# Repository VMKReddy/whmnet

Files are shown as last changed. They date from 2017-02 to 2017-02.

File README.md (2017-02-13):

# whmnet

The whmnet project consists in:
- A wireless sensor network which performs temperature, atmospheric pressure and relative humidity measurements
- A gateway which receives the measurements and pass them to a Raspberry Pi
- A Raspberry Pi which is connected to the Internet, posting measurements on a webserver
- A web server hosting the measurements database and a web application to display the date

# The Sensor

The wireless sensor is a custom PCB based on:
- A STM32L0 ARM-Cortex M0 microcontroler which gathers data from sensors and send them over the air
- SHT21 Relative Humdity Sensor - I2C
- MS5637 Barometric Pressure Sensor - I2C
- CC1101 868MHz transceiver from Texas Instruments - SPI
- On-board 868MHz ceramic antenna and IPC device (balun + filter + match)
- All of this is powered by a CR2450 lithium coin cell downconverted to 2.1V by TPS62730 ultra-low-power DC-DC converter

The wireless sensor performs a measurement every 5 minutes and goes back to low-power mode between each measurement, achieving an ultra-low-power average consumption of 5µA leading to several months of battery life.

The PCB design files are available in the [SensorBoard](./SensorBoard/) directory. It has been designed with Altium Designer.

The MCU firmware is available in the [Sensor](./Sensor/) directory. [SW4STM32](http://www.openstm32.org) Eclipse based IDE from AC6 has been used. The toolchain is GCC-based, and the (free) IDE is part of the STMicroelectronics Open Development Environment. BSP has been generated with [STM32CubeMX](http://www.st.com/en/development-tools/stm32cubemx.html) tool and the [STM32CubeL0](http://www.st.com/en/embedded-software/stm32cubel0.html) open-source library is used.

# The Gateway

The gateway consists in:
- A custom board for wireless reception
- A Raspberry Pi 2 model B

## Gateway RF Board

The custom board includes:
- An STM32L0 microcontroler
- A CC1120 RF transceiver for wireless communication
- A green LED indicating radio packet Rx

The STM32L0 reports the measurements from wireless sensors to the Raspberry Pi using the serial port.

The PCB design files are available in the [GatewayBoard](./GatewayBoard/) directory.
The MCU firmware of the Gateway Board is available in the [Gateway](./Gateway/) directory.

## Raspberry Pi

The Raspberry Pi:
- Receives measurements from the custom board over the UART
- Check data validity (by controlling CRC values)
- Push the data on a webserver on the internet

Failures, hangs, loss of internet connection, etc. are all taken care of by dedicated scripts and watchdogs which perform data backup, retries, process monitoring and eventually reboots.

# The webserver

The webserver, hosted on the internet:
- stores data coming from the Gateway
- run a web application for data display

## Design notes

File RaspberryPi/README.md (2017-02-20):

## Raspberry Pi software

### Description

A Raspberry Pi model B+ running Raspbian Jessie is used to post the measurements on the web.
The python script readGateway.py is used to communicate with the Gateway.

The Gateway reports measurements coming from wireless sensors to the Raspberry Pi through the serial port (pins 8 & 10 of the Raspberry Pi model B header).

Communication is unidirectionnal (Gateway --> Raspberry Pi).

After receiving raw data from the Gateway, the script extracts measurements (temperature, pressure, RH) and posts them on a dedicated server on the web.

### Dependencies

The script is run with python 2.7.6.
The following external packages are needed:
- [requests](http://docs.python-requests.org/en/master/) (to perform http requests)
- [crcmod](https://pypi.python.org/pypi/crcmod) (for custom CRC calculations)

You can install these two packages with pip for instance.

### Configuration

Edit the configTemplate.py script to match your configuration (logging level, webserver parameters, ...). Then rename it to config.py or modify readGateway.py to import the right script. 

### Monitoring script execution

#### Monitoring script

The shell script [readGatewayMonitor](readGatewayMonitor) is used to restart the python script if it crashes.
Modify the paths to match your configuration if you want to use it.

#### Crontab

A crontab entry is used to start the readGatewayMonitor script at boot time.

Use ```sudo crontab -e``` to edit the crontab and then add the following entry (change path to math your installation):
```
@reboot /home/pi/templog_gateway/readGatewayMonitor
```

#### Logrotate

The python script logs data to a log file each time a message is received from the Gateway, or only on errors, depending on the logger configuration (see script).

Logrotate tool is used to keep logfile small and delete oldest logs automatically. It is not shipped with Raspbian by default so you may need to install it manually with ```apt-get install```.

Configuration of logrotate for our use is in [logrotate.d](logrotate.d/).
Simply copy [templog](logrotate.d/templog) to ```/etc/logrotate.d/``` on your Pi, and edit it so the paths match your installation.

### Additionnal considerations

In the actual setup, the Raspberry Pi is left unattented for several months. The hardware watchdog has been configured on the Pi to reboot the system in case of a major failure or undetected bugs remaining in the python script.

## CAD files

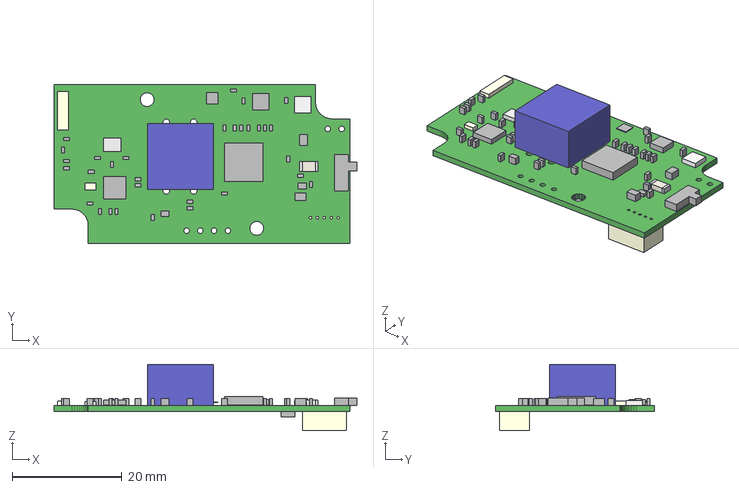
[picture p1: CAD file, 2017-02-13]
SensorBoard/Project Outputs for SensorNode/PCB.step
55.3 x 29.0 x 12.1 mm
Board
Extruded x 50

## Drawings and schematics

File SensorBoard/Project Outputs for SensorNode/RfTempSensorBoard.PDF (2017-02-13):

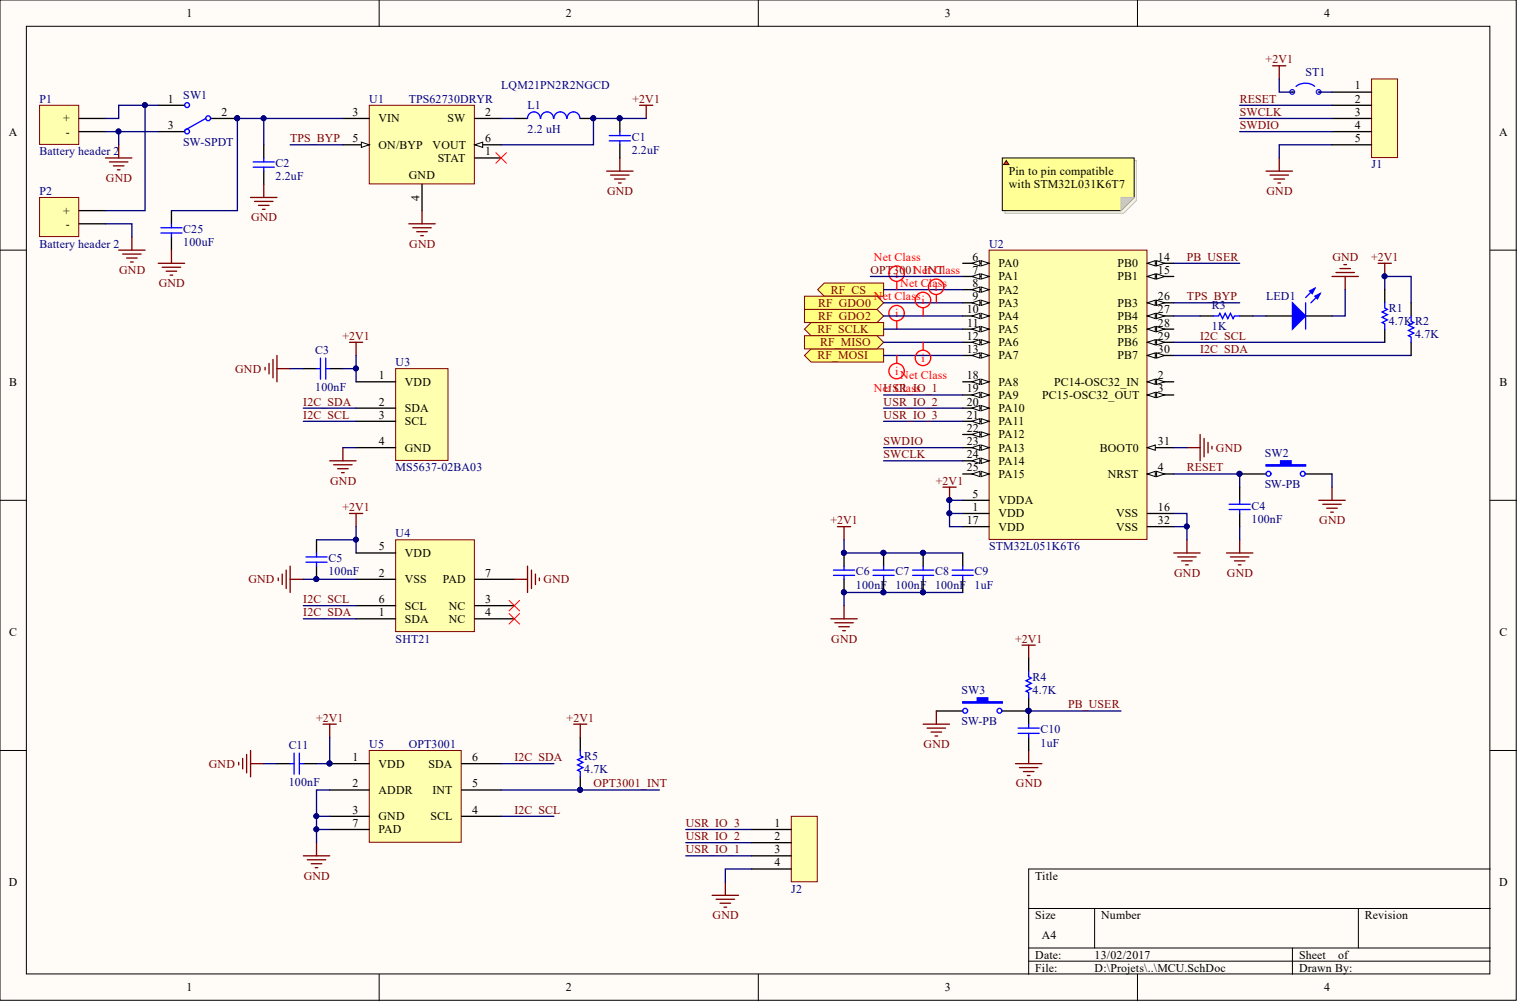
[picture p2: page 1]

Pin to pin compatible
with STM32L031K6T7

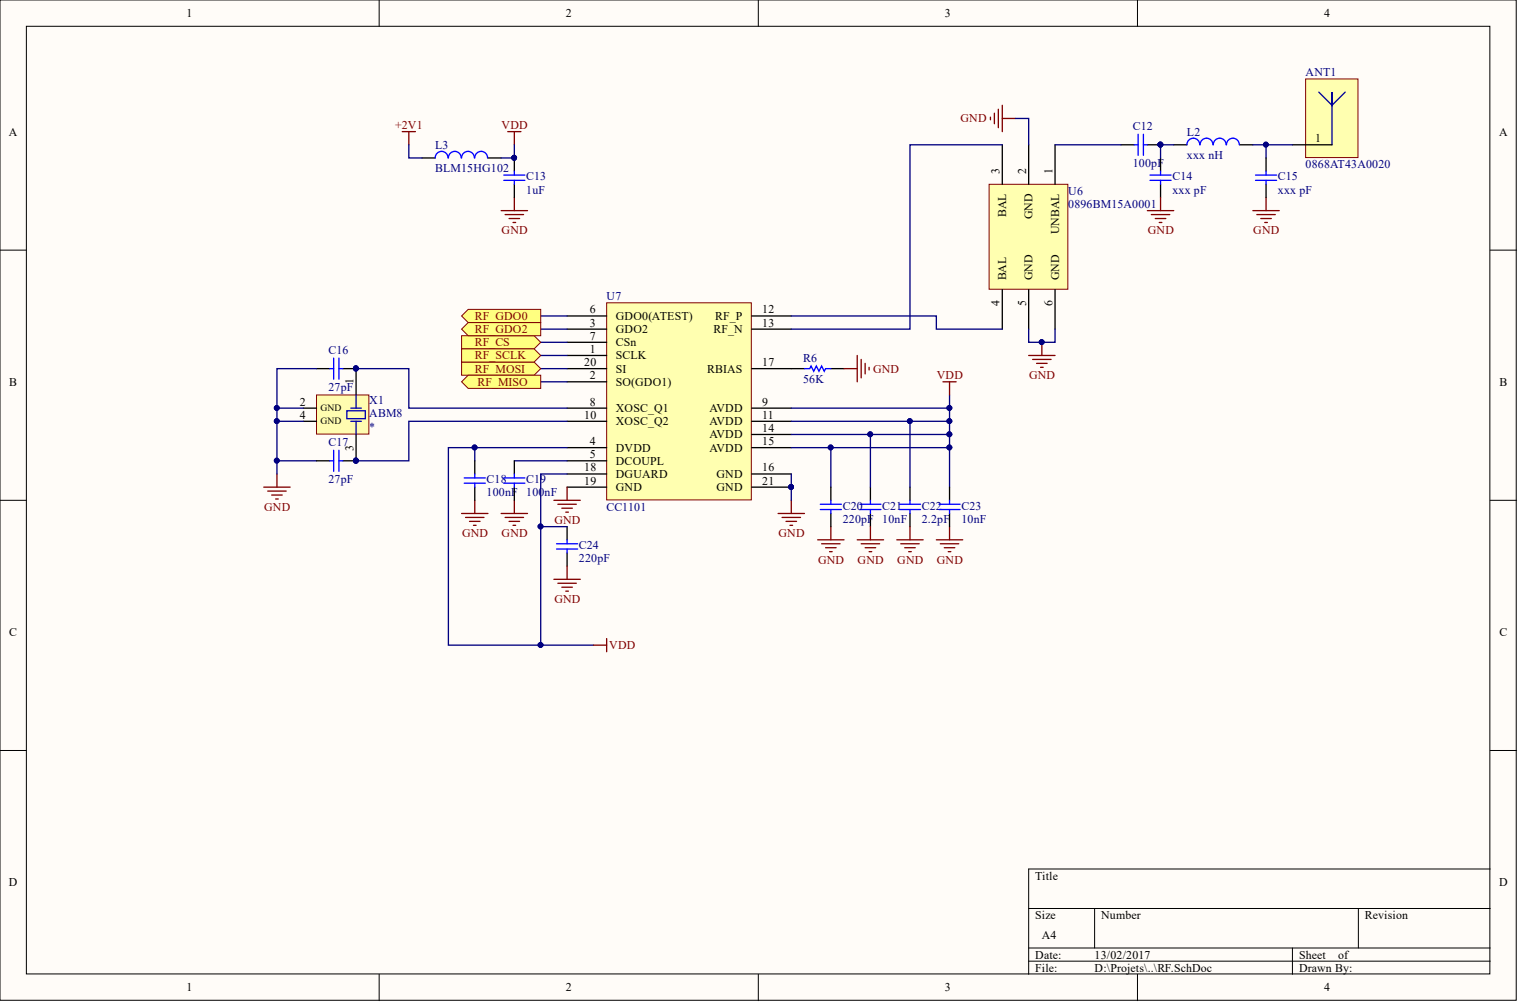
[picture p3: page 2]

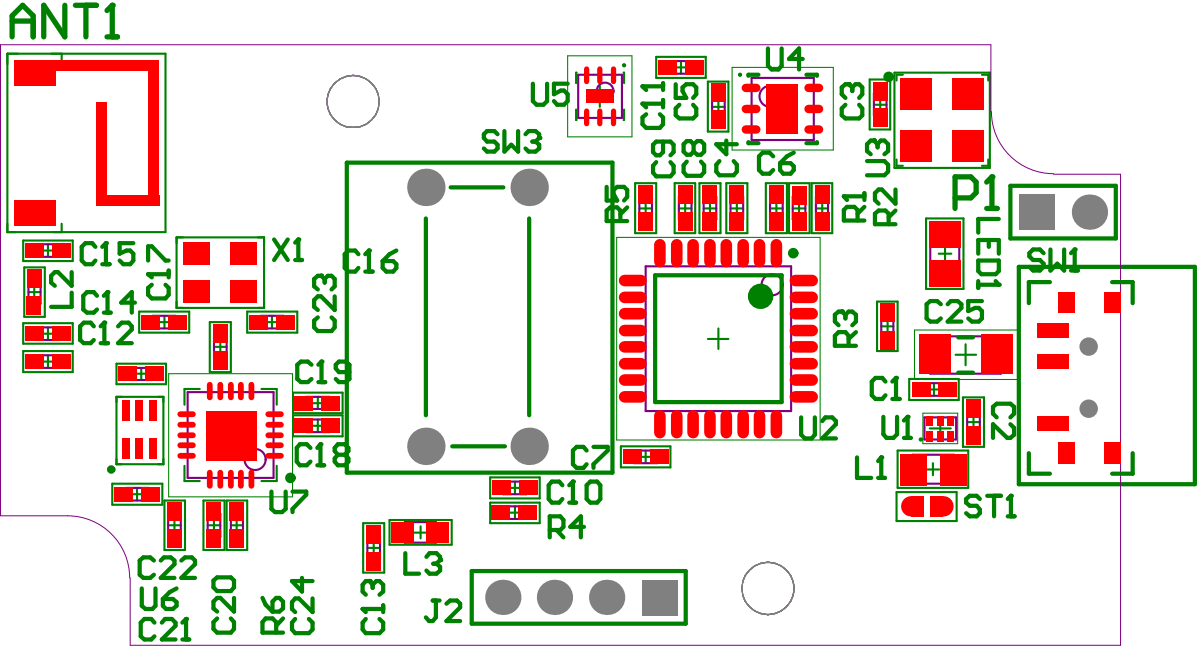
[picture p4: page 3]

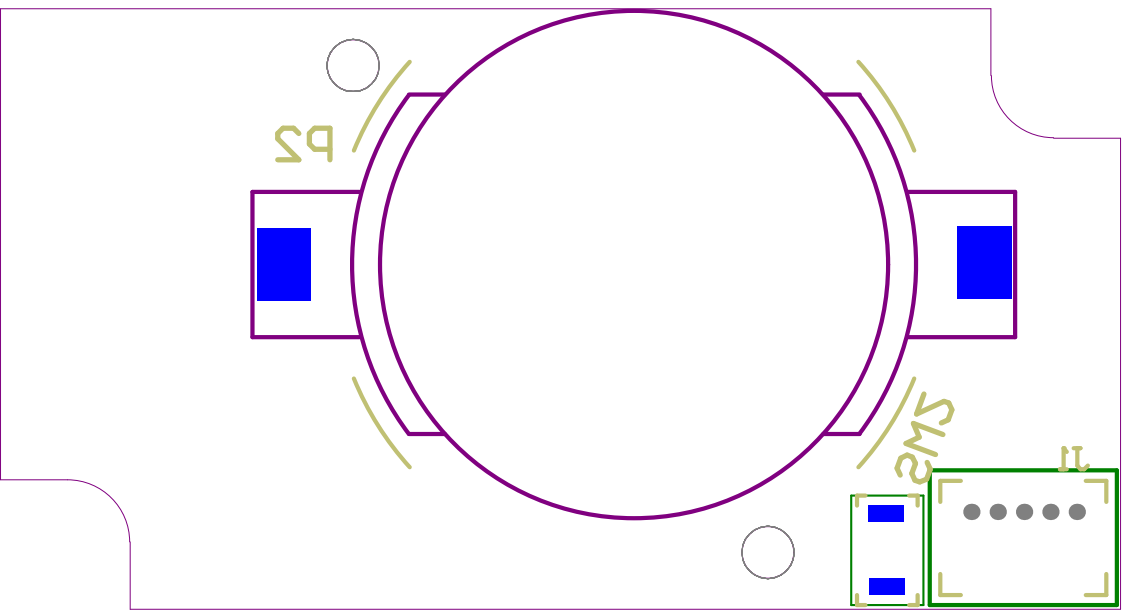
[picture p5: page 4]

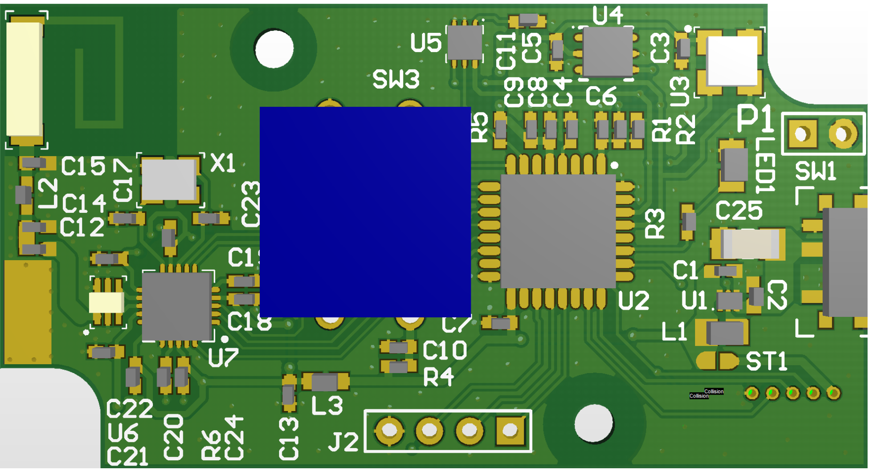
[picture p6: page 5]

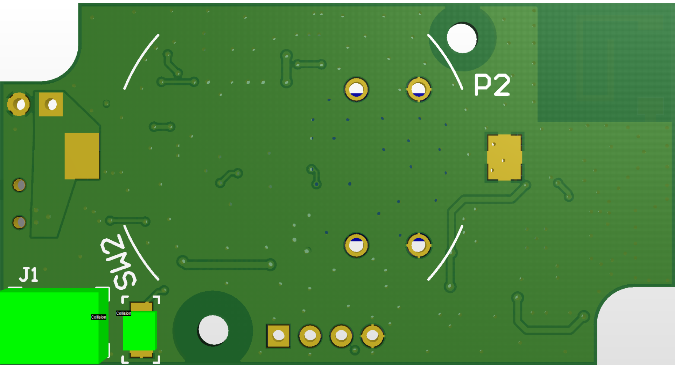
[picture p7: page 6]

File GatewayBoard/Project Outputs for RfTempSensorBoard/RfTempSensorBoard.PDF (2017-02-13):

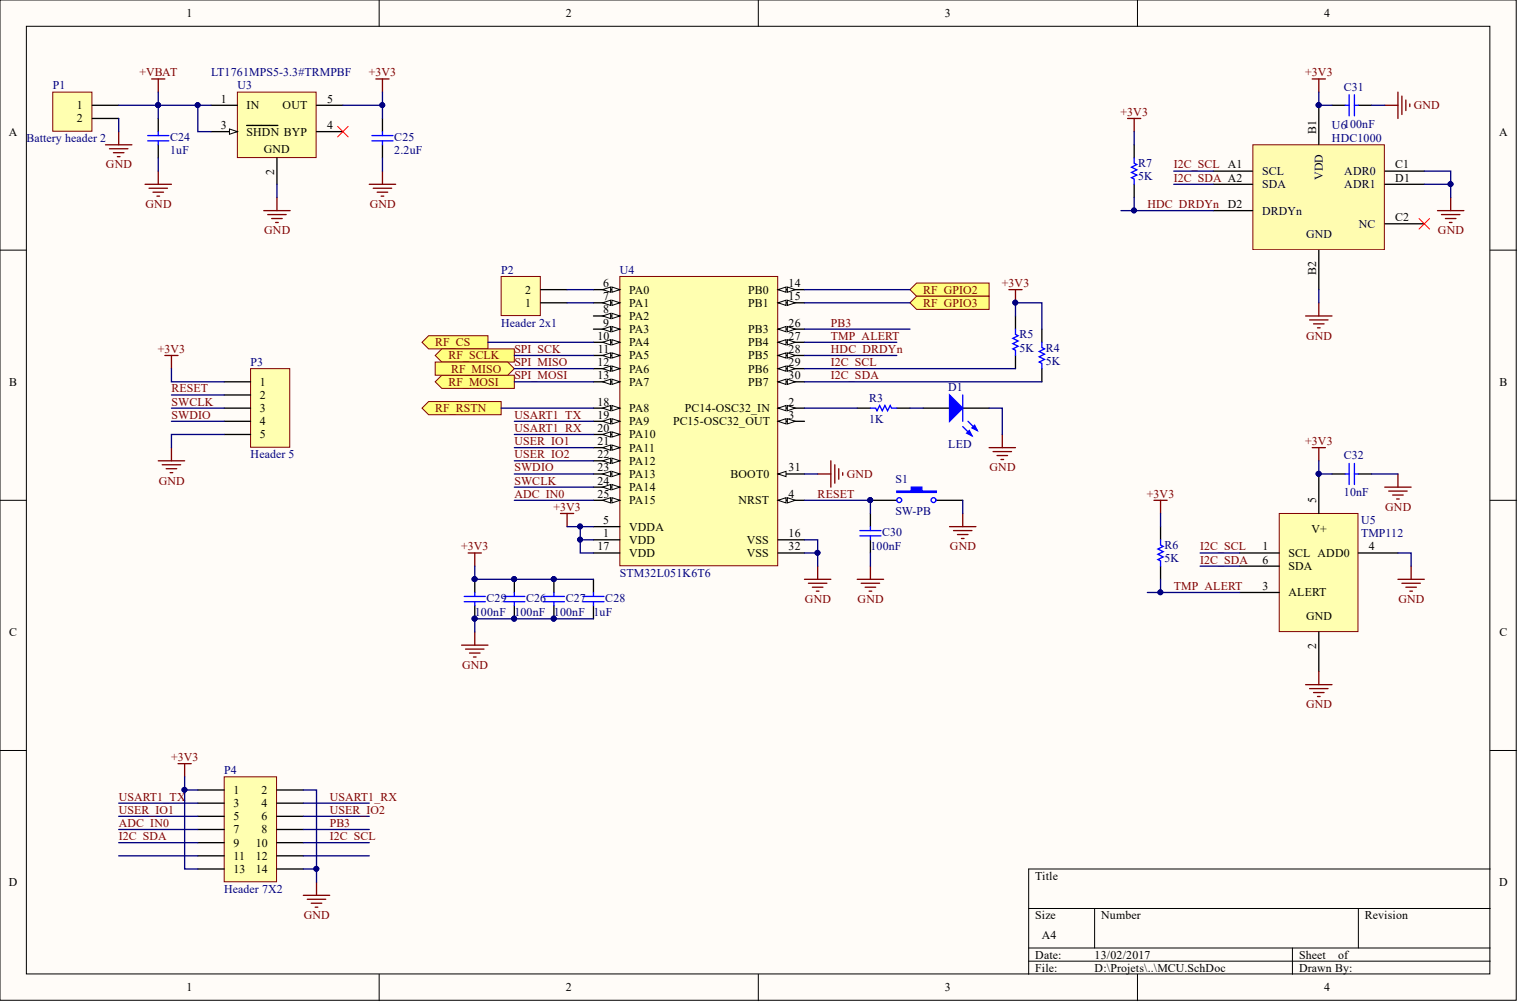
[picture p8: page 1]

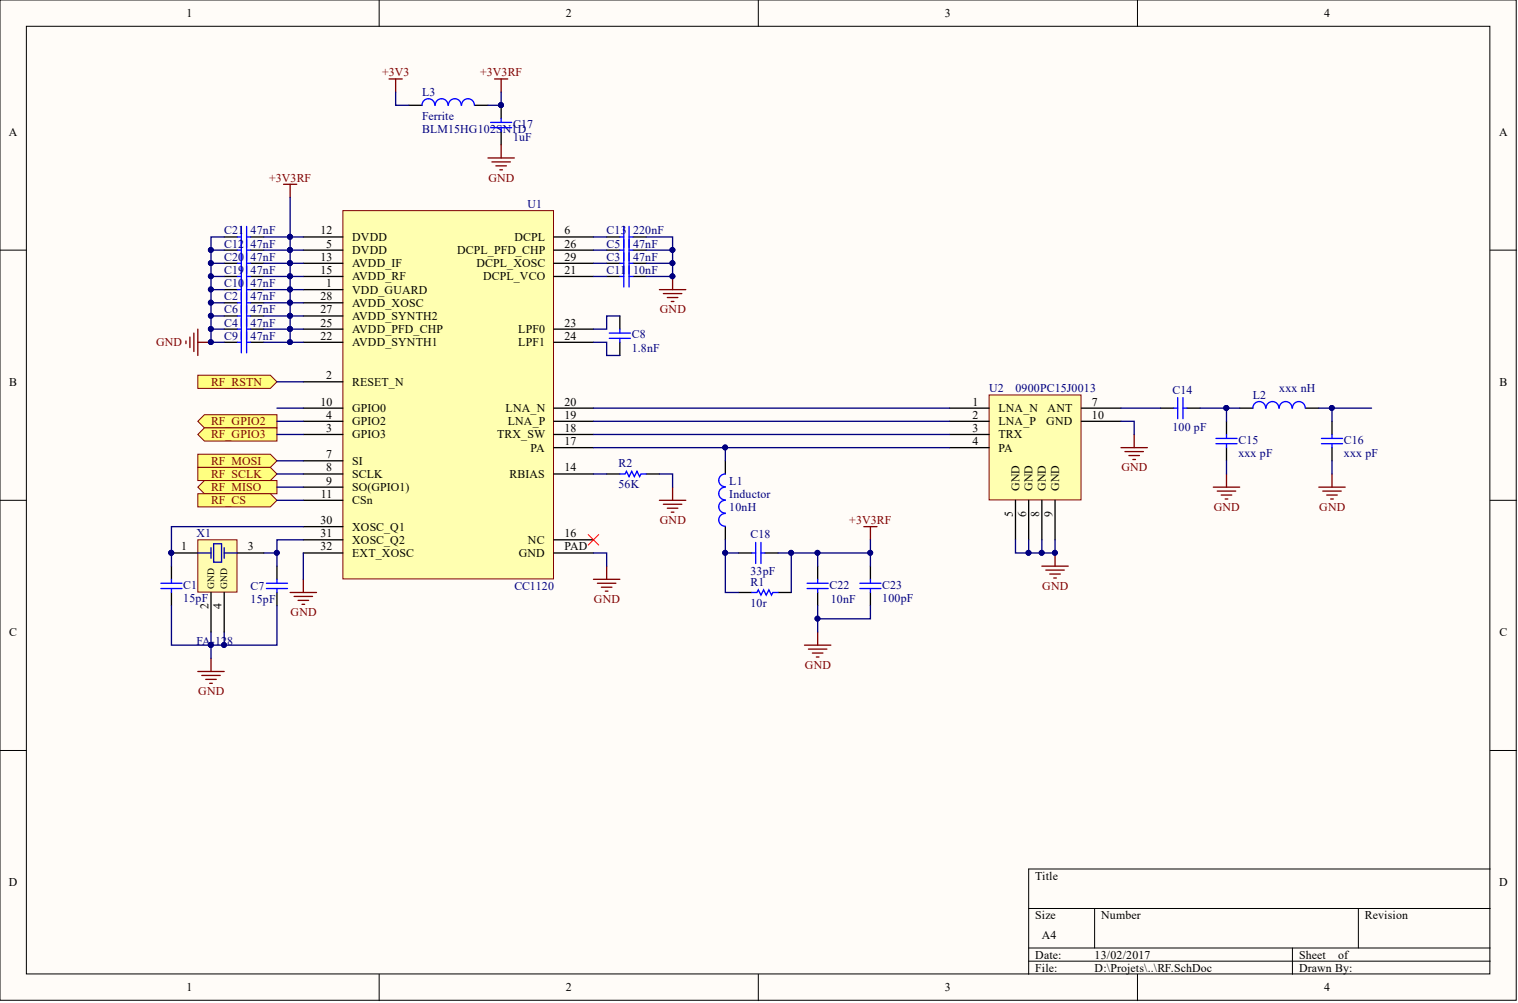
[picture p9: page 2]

C1 | 4 7 n F | 5 | 2 6 C5 | 4 7 | n F
C2 | 4 7 n F | 1 3 | 2 9 C3 | 4 7 | n F
C1 | 4 7 n F | 1 5 | 2 1 C1 | 1 0 | n F
C1 | 4 7 n F | 1
C2 | 4 7 n F | 2 8
C6 | 4 7 n F | 2 7
C4 | 4 7 n F | 2 5
C9 | 4 7 n F | 2 2

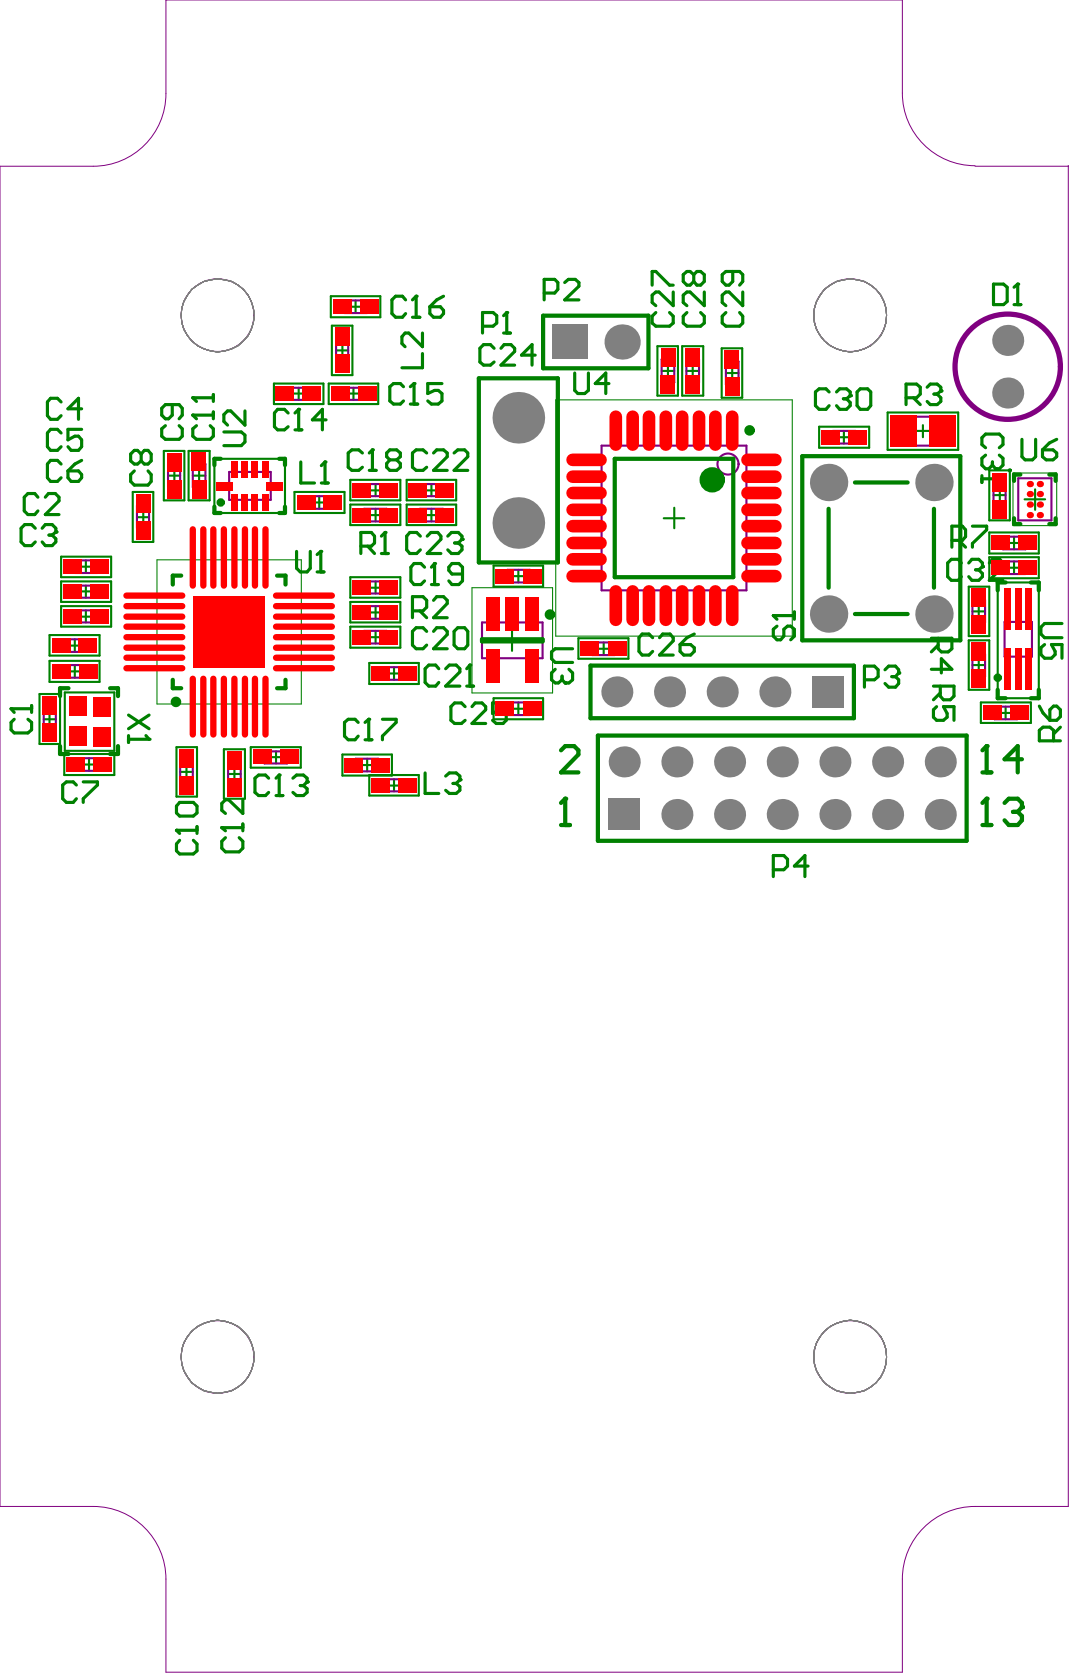
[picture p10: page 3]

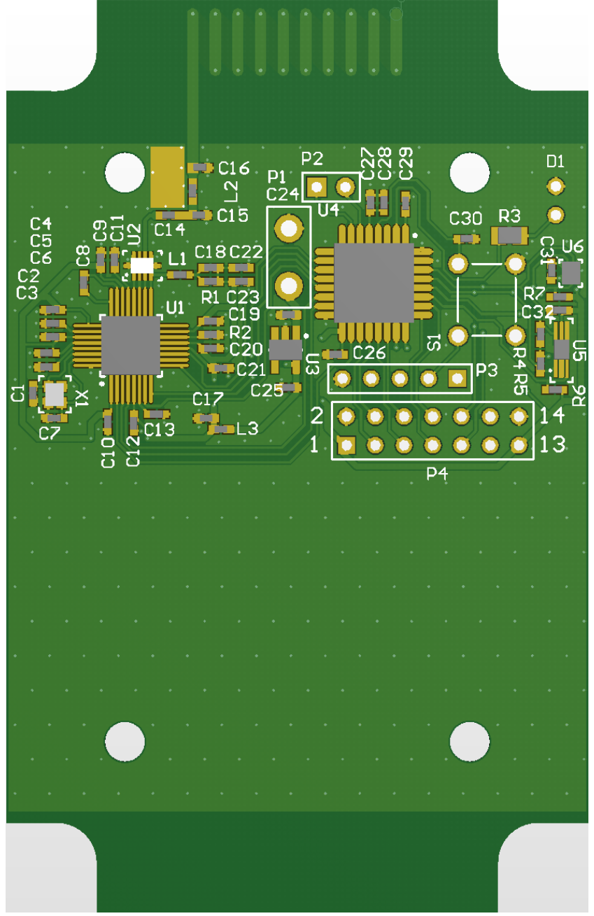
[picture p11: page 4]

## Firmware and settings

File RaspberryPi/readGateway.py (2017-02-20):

#!/usr/bin/python
# -*- coding: utf-8 -*-

"""
    readGateway.py script
    =====================

    This script is used in the whmnet project to receive data from the
    wireless network gateway and send it to a custom server on the web.
    This script is run on a Raspberry Pi, connected to the Gateway 
    through the UART serial port on the Pi GPIO header.
"""
# built-in modules
import serial
import binascii
import struct
import datetime
import logging
import logging.handlers

# third-party modules
import crcmod
import requests

# Import configuration variables
from config import *

# Constants
FILE_TYPE_GW_LOG        = 0
FILE_TYPE_SENSOR_LOG    = 1
FILE_TYPE_LEGACY_DATA   = 2
FILE_TYPE_DATA          = 3

GW_TYPE_REMOTE_DATA   = 0
GW_TYPE_LOCAL_DATA    = 1
GW_TYPE_LOG           = 2

SENS_TYPE_DATA        = 0
SENS_TYPE_LOG         = 1
SENS_TYPE_DATA_LEGACY = 2

logger = logging.getLogger()

def main():

    # Configure logger
    wfh = logging.handlers.WatchedFileHandler(cfgLoggerFile) # log file
    formatter = logging.Formatter('%(asctime)s - %(levelname)s: %(message)s') # log header
    wfh.setFormatter(formatter)
    logger.addHandler(wfh)
    logger.setLevel(cfgLogLevel) # set level according to your needs

    # Configure CRC with polynome, reversing etc.
    crc32_func = crcmod.mkCrcFun(0x104C11DB7, initCrc=0x0, rev=True, xorOut=0xFFFFFFFF)

    # Open serial port to communicate with gateway
    try:
        logger.info('Opening serial port.')
        port = serial.Serial(cfgSerialName, cfgSerialSpeed, timeout=None)
    except serial.SerialException:
        logger.critical('Serial port unavailable')
        raise
    else:
        logger.info('Serial port successfully opened.')

    # main loop
    while True:

        # search for sync byte 0xAA
        rcv = port.read(1)
        if rcv == b'\xAA':
            logger.debug('Sync word received.')

            # Get timestamp
            timedata = datetime.datetime.now()

            # Proceed with message
            # First byte is length of UART frame
            # use ord() because data is written in binary format on UART by STM32 (not char)
            length = ord(port.read(1)) 
            logger.debug('Size of rcvd frame: ' + str(length))

            # We can have length = 0 if rx uart buffer is full (in case python script
            # is started after sensor gateway)
            if length > 0:

                # Then read the entire frame
                msg = port.read(length)
                logger.debug('Rx frame: ' + binascii.hexlify(msg))

                # Unpack the CRC from the 4 last bytes of frame
                try:
                    rxcrc = struct.unpack('<I', msg[length-4:length])[0]
                except struct.error:
                    logger.exception('CRC struct error.')
                else:
                    logger.debug('Rx CRC: ' + str(rxcrc) + ' - ' + hex(rxcrc))

                # Compute CRC on frame data (except sync and length bytes)
                compcrc = crc32_func(msg[0:length-4])
                logger.debug('Calculated CRC: ' + str(compcrc) + ' - ' + hex(int(compcrc)))

                # Compare rcvd CRC and calculated CRC
                if rxcrc != int(compcrc):
                    # A problem occured during UART transmission
                    logger.info('CRC ERROR.')
                else:
                    # Get message type from Gateway
                    gwMsgType = ord(msg[0]);

                    # Remote data is data coming from wireless sensors
                    if gwMsgType == GW_TYPE_REMOTE_DATA:
                        
                        # get sensor id and msg type
                        sensMsgType = ord(msg[2]) >> 4
                        sensorId = ord(msg[2]) & 0xf
                       
                        # get RSSI (can be negative)
                        rssi = ord(msg[length-6])
                        if rssi > 127:
                            rssi = (256 - rssi) * (-1)

                        # Print sensor ID
                        logger.info('Sensor ID: ' + str(sensorId) + ' - RSSI: ' + str(rssi))

                        # log/error message from sensor
                        if sensMsgType == SENS_TYPE_LOG:
                            
                            # print and process log message
                            log_msg = binascii.hexlify(msg[3:6])
                            logger.info('Log message: ' + log_msg)
                            
                            # Write msg to file
                            writeSensorLog(sensorId, timedata, log_msg, rssi)
                            # Post msg on server
                            postMeasFromFile()

                        # measurement message from V1 sensor (not used anymore)
                        elif sensMsgType == SENS_TYPE_DATA_LEGACY:

                            # Extract and print temperature #
                            temperature = computeTemp(msg[3:5])
                            logger.debug('Temperature: ' + str(temperature))
    
                            # Write measurement to file
                            writeLegacyData(sensorId, timedata, temperature, rssi)

                            # Post measurement on server
                            postMeasFromFile()
                        
                        # measurement message from V2 sensor
                        elif sensMsgType == SENS_TYPE_DATA:
                            
                            #Extract data from message
                            data = computeData(msg[3:8])
                            logger.info('Temp: ' + '{:.2f}'.format(data['temp']))
                            logger.info('Hum: ' + '{:.2f}'.format(data['hum']))
                            logger.info('Pres: ' + str(data['pres']))

                            # Write data to file
                            writeData(sensorId, timedata, data['temp'], data['hum'], data['pres'], rssi)

                            # Post on server
                            postMeasFromFile()

                        else:
                            logger.warning('UNKNOWN SENSOR MSG TYPE.') 
                    
		            # log message from gateway itself
                    elif gwMsgType == GW_TYPE_LOG:
                        # Print log message
                        logger.info('Gateway log: ' + str(ord(msg[1])))
                        # Write msg to file
                        writeGatewayLog(timedata, ord(msg[1]))
                        # Post msg on server
                        postMeasFromFile()
                   
                    else:
                        logger.warning('UNKNOWN GATEWAY MSG TYPE.') 

            else:
                logger.error('Gateway msg is of length 0.')



# The 4 functions below save posts to the CSV buffer file before they are sent to the server
def writeLegacyData(id, timedata, temp, rssi):
    with open(cfgBufferFile, 'a') as f:
        f.write(str(id) + ',' + str(FILE_TYPE_LEGACY_DATA) + ',' +
                timedata.strftime("%Y-%m-%d %H:%M:%S") + ',' +
                str(temp) + ',' + str(rssi))
        f.write('\n')

def writeData(id, timedata, temp, hum, pres, rssi):
    with open(cfgBufferFile, 'a') as f:
        f.write(str(id) + ',' + str(FILE_TYPE_DATA) + ',' + timedata.strftime("%Y-%m-%d %H:%M:%S") + ',' + 
                '{:.2f}'.format(temp) + ',' + '{:.2f}'.format(hum) + ',' + str(pres) + ',' + str(rssi))
        f.write('\n')

def writeSensorLog(id, timedata, log, rssi):
    with open(cfgBufferFile, 'a') as f:
        f.write(str(id) + ',' + str(FILE_TYPE_SENSOR_LOG) + ',' + timedata.strftime("%Y-%m-%d %H:%M:%S") +
                ',' + str(log) + ',' + str(rssi))
        f.write('\n')

def writeGatewayLog(timedata, log):
    with open(cfgBufferFile, 'a') as f:
        f.write('255' + ',' + str(FILE_TYPE_GW_LOG) + ',' + timedata.strftime("%Y-%m-%d %H:%M:%S") + ',' + str(log))
        f.write('\n')

# Function to compute temperature from V1 sensor message (not for V2 sensor)
def computeTemp(tempString):
    # unpack data - big endian 16 bit
    try:
        temp = struct.unpack('>h', tempString)[0]
    except struct.error:
        logger.exception('Temperature struct error.')
        return -99
    else:
        # Convert code to actual temperature
        temp = temp * 0.0625 # 1 LSB = 0.0625 °C
        return temp

# Function to extract temperature, RH and pressure data from sensor V2 message
# See sensor V2 STM32L0 firmware source to retrieve message structure
def computeData(dataStr):

    # Initialize dictionnary
    data = {}

    #fixme: return errors and check for error in calling function

    # Little endian 24-bit padded to 32
    try:
        sht = struct.unpack('<I', dataStr[0:3] + '\x00')
    except struct.error:
        logger.exception('SHT21 data decoding struct error.')
        return -99
    else:
        data['temp'] = -46.85 + 175.72 * ((sht[0] & 0x7FF) << 5) / pow(2,16)
        data['hum']  = -6.0 + 125.0 * ((sht[0] >> 11) << 5) / pow(2,16)


    # Little endian 16-bit
    try:
        ms56 = struct.unpack('<H', dataStr[3:5])
    except struct.error:
        logger.exception('MS5637 data decoding struct error.')
        return -99
    else:
        data['pres'] = ms56[0] + 85000

    return data


# Function that reads the CSV buffer file line by line and post the data to the
# webserver if it is reachable on the internet
def postMeasFromFile():
    nbLinesPosted = 0

    # open backup file in read mode
    with open(cfgBufferFile, 'r') as f:
        # Save all measurements in lines variable
        lines = f.readlines() 

        # Go back to start of file and read it line by line
        f.seek(0, 0)   
        for line in f:
            # Remove newline character
            line = line.rstrip('\n')
            # Split the line to get the items in a list
            s = line.split(',', -1)
            if len(s) != 0:
                # Try to post measurement on server
                type = int(s[1])
                if type == FILE_TYPE_GW_LOG:
                    status = postOnServer(s[0], s[1], s[2], s[3], '', '', '', '')

                elif type == FILE_TYPE_SENSOR_LOG:
                    status = postOnServer(s[0], s[1], s[2], s[3], '', '', '', s[4])
                    
                elif type == FILE_TYPE_LEGACY_DATA:
                    status = postOnServer(s[0], s[1], s[2], '', s[3], '', '', s[4])

                elif type == FILE_TYPE_DATA:
                    status = postOnServer(s[0], s[1], s[2], '', s[3], s[4], s[5], s[6])
                else:
                    logger.error('Unknow type in data file.')
                    status = 200
                
                # If posting is successful, increment variable else break
                if status != 200:
                    break
                else:
                    nbLinesPosted = nbLinesPosted + 1
            else:
                # simply ignore line
                logger.error('Invalid line in file. Skipping.')
                nbLinesPosted = nbLinesPosted + 1

    # Open the file not appending write mode
    with open(cfgBufferFile, 'w') as f:
        # Write all lines that were not posted on server
        f.writelines(lines[nbLinesPosted:])           
        
# Function to post data on websever. Uses the requests package.
def postOnServer(id_s, dataType_s, datetime_s, log_s, temp_s, hum_s, pres_s, rssi_s):
    retval = 0;
    payload = {'id': id_s, 'type': dataType_s, 'time': datetime_s,
            'temp': temp_s, 'hum': hum_s, 'pres': pres_s,
            'log': log_s, 'rssi': rssi_s, 'chk': cfgPostPwd}
    logger.debug(payload)
    try:
        r = requests.post(cfgPostUrl, data=payload, timeout=5)
    except requests.exceptions.ConnectionError:
        logger.exception('Connection error')
    except requests.exceptions.HTTPError:
        logger.exception('HTTP invalid response error.')
    except requests.exceptions.Timeout:
        logger.exception('Connection timeout error.')
    except requests.exceptions.TooManyRedirects:
        logger.exception('Too many redirects.')
    else:
        retval = r.status_code
        logger.debug(r.text)
    return retval

if __name__ == "__main__":
    main()

__author__ = "Lucas Glénat"
__copyright__ = "Copyright 2017, whmnet project"
__credits__ = ["Lucas Glénat"]
__license__ = "GPLv3"
__version__ = "1.0.0"
__maintainer__ = "Lucas Glénat"
__email__ = "lucasglenat@hotmail.com"
__status__ = "Production"

#### END OF FILE ####

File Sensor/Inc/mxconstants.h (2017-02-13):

/**
  ******************************************************************************
  * File Name          : mxconstants.h
  * Description        : This file contains the common defines of the application
  ******************************************************************************
  */

/* Define to prevent recursive inclusion -------------------------------------*/
#ifndef __MXCONSTANT_H
#define __MXCONSTANT_H
  /* Includes ------------------------------------------------------------------*/

/* Private define ------------------------------------------------------------*/

#define CC1101_CS_Pin GPIO_PIN_2
#define CC1101_CS_GPIO_Port GPIOA
#define CC1101_GDO0_Pin GPIO_PIN_3
#define CC1101_GDO0_GPIO_Port GPIOA
#define CC1101_GDO2_Pin GPIO_PIN_4
#define CC1101_GDO2_GPIO_Port GPIOA
#define PB_USER_Pin GPIO_PIN_0
#define PB_USER_GPIO_Port GPIOB
#define USR_IO_1_Pin GPIO_PIN_9
#define USR_IO_1_GPIO_Port GPIOA
#define USR_IO_2_Pin GPIO_PIN_10
#define USR_IO_2_GPIO_Port GPIOA
#define USR_IO_3_Pin GPIO_PIN_11
#define USR_IO_3_GPIO_Port GPIOA
#define TPS_BYP_Pin GPIO_PIN_3
#define TPS_BYP_GPIO_Port GPIOB
#define LED_Pin GPIO_PIN_4
#define LED_GPIO_Port GPIOB

#endif /* __MXCONSTANT_H */
/****END OF FILE****/

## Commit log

2017-02-13 Initial commit of Gateway and Sensor firmware.
    [Gateway.cfg, SensorNode.cfg]
2017-02-13 Initial commit of Gateway board design files.
    [MCU.SchDoc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]
2017-02-13 Initial commit of Sensor board design files.
    [MCU.SchDoc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]
2017-02-20 Initial commit of RaspberryPi software.
